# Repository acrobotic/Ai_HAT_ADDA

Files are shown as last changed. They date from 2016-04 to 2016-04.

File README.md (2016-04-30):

## Ai\_HAT\_ADDA

PCB design files (EAGLE) of a Raspberry Pi A+/B+/2/3 HAT with four 16-Bit Analog
Inputs (ADS1115) and two 12-Bit Analog Outputs (MCP4725).

## Description

Visit our online shop at:

   * https://acrobotic.com/

Designed by ACROBOTIC Industries.  Please consider buying products from us to 
help fund future Open-Source projects like this! We’ll always put our best 
effort in every project, and release all our design files and code for you to 
use. 

## License

Released under the Creative Commons Attribution, Share-Alike license. Please 
check LICENSE.txt for more information. All text above must be included in any 
redistribution.

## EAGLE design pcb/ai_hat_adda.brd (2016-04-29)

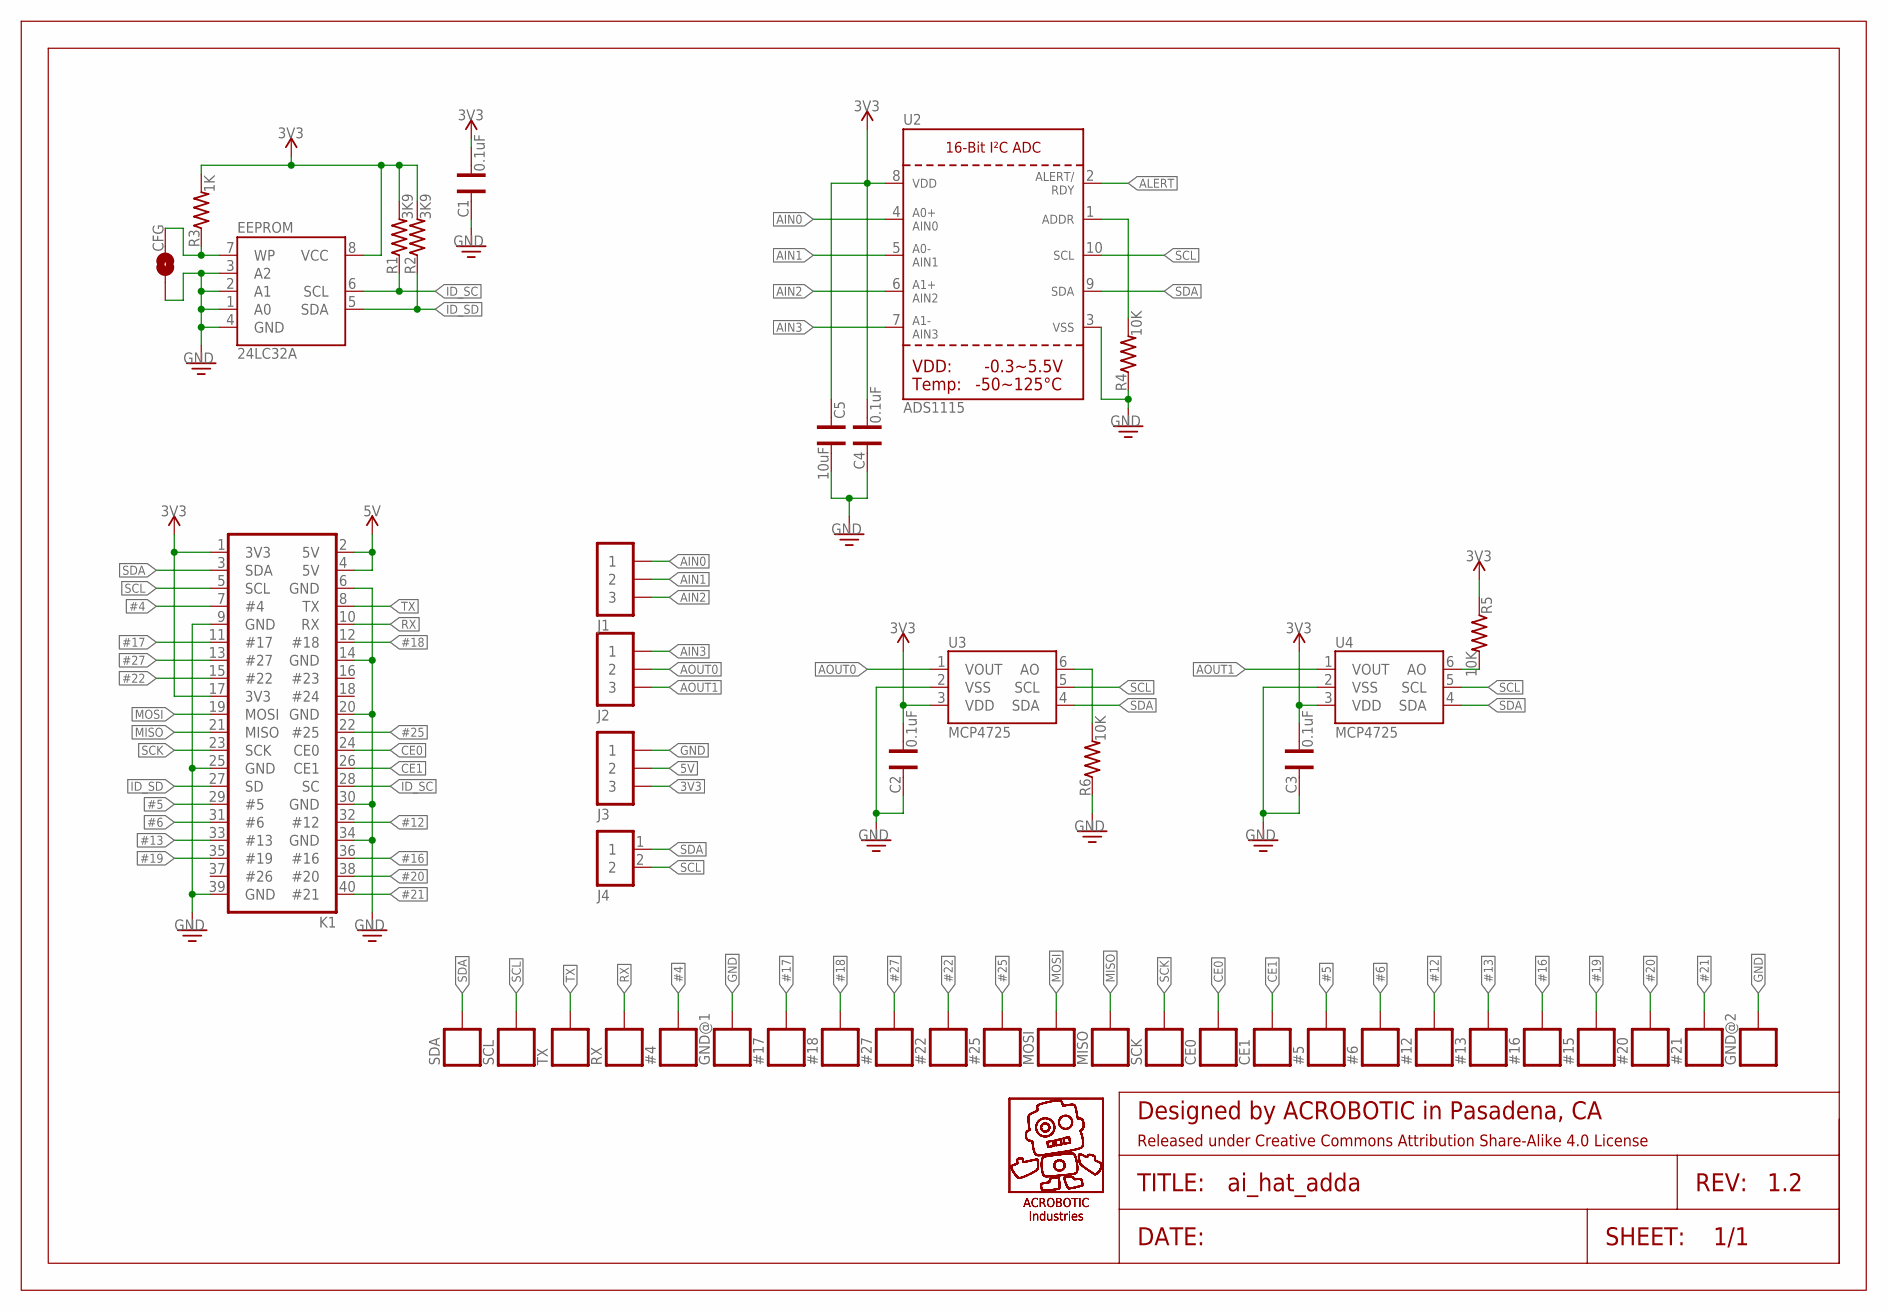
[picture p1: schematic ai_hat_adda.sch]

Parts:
#4, #5, #6, #12, #13, #15, #16, #17, #18, #20, #21, #22, #25, #27: 1X01-SM
C1: 0.1uF; CAP-0603
C2, C3, C4: 0.1uF; CAP-0402
C5: 10uF; CAP-0402
CE0, CE1: 1X01-SM
CFG: 1X02-SJ-NO
EEPROM: 24LC32A; SO08-EIAJ
FRAME1: FRAME-LETTER; CREATIVE-COMMONS
GND@1, GND@2: 1X01-SM
J1, J2, J3: 1X03ST; 1X03-ST
J4: 1X02ST; 1X02-ST
K1: 2X20-RPI-ALT
MISO: 1X01-SM
MOSI: 1X01-SM
R1, R2: 3K9; RES-0603; TOLERANCE 5%
R3: 1K; RES-0603; TOLERANCE 5%
R4, R5, R6: 10K; RES-0402
RX: 1X01-SM
SCK: 1X01-SM
SCL: 1X01-SM
SDA: 1X01-SM
TX: 1X01-SM
U2: ADS1115; MSOP10
U3, U4: MCP4725; SOT23-6
U$9, U$10: AI-LOGOXS; AI-LOGO-XS

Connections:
3V3: C1.1, C2.1, C3.1, C4.1, C5.2, EEPROM.8 (VCC), J3.3, K1.1 (3V3), K1.17 (3V3), R1.2, R2.2, R3.2, R5.1, U2.8 (VDD), U3.3 (VDD), U4.3 (VDD)
5V: J3.2, K1.2 (5V), K1.4 (5V)
#4: #4.1, K1.7 (#4)
#5: #5.1, K1.29 (#5)
#6: #6.1, K1.31 (#6)
#12: #12.1, K1.32 (#12)
#13: #13.1, K1.33 (#13)
#16: #16.1, K1.36 (#16)
#17: #17.1, K1.11 (#17)
#18: #18.1, K1.12 (#18)
#19: #15.1, K1.35 (#19)
#20: #20.1, K1.38 (#20)
#21: #21.1, K1.40 (#21)
#22: #22.1, K1.15 (#22)
#25: #25.1, K1.22 (#25)
#27: #27.1, K1.13 (#27)
AIN0: J1.1, U2.4 (AIN0)
AIN1: J1.2, U2.5 (AIN1)
AIN2: J1.3, U2.6 (AIN2)
AIN3: J2.1, U2.7 (AIN3)
ALERT: U2.2 (ALERT/RDY)
AOUT0: J2.2, U3.1 (VOUT)
AOUT1: J2.3, U4.1 (VOUT)
CE0: CE0.1, K1.24 (CE0)
CE1: CE1.1, K1.26 (CE1)
GND: C1.2, C2.2, C3.2, C4.2, C5.1, CFG.1, EEPROM.1 (A0), EEPROM.2 (A1), EEPROM.3 (A2), EEPROM.4 (GND), GND@1.1, GND@2.1, J3.1, K1.6 (GND), K1.9 (GND), K1.14 (GND), K1.20 (GND), K1.25 (GND), K1.30 (GND), K1.34 (GND), K1.39 (GND), R4.1, R6.1, U2.3 (VSS), U3.2 (VSS), U4.2 (VSS)
ID_SC: EEPROM.6 (SCL), K1.28 (SC), R1.1
ID_SD: EEPROM.5 (SDA), K1.27 (SD), R2.1
MISO: K1.21 (MISO), MISO.1
MOSI: K1.19 (MOSI), MOSI.1
unnamed: R4.2, U2.1 (ADDR)
unnamed: R6.2, U3.6 (AO)
unnamed: CFG.2, EEPROM.7 (WP), R3.1
unnamed: R5.2, U4.6 (AO)
RX: K1.10 (RX), RX.1
SCK: K1.23 (SCK), SCK.1
SCL: J4.2, K1.5 (SCL), SCL.1, U2.10 (SCL), U3.5 (SCL), U4.5 (SCL)
SDA: J4.1, K1.3 (SDA), SDA.1, U2.9 (SDA), U3.4 (SDA), U4.4 (SDA)
TX: K1.8 (TX), TX.1

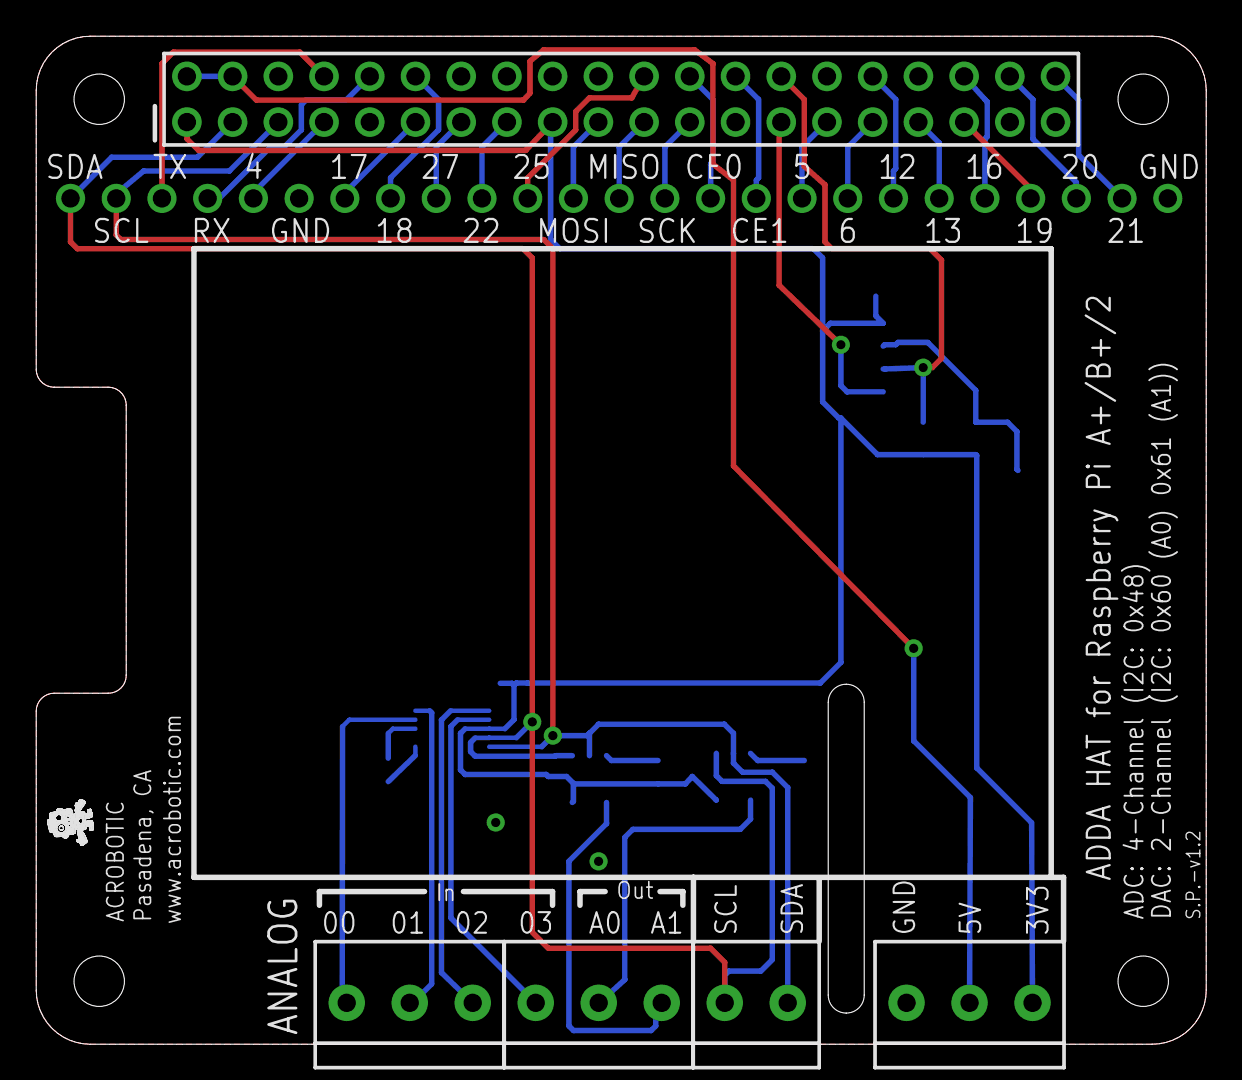
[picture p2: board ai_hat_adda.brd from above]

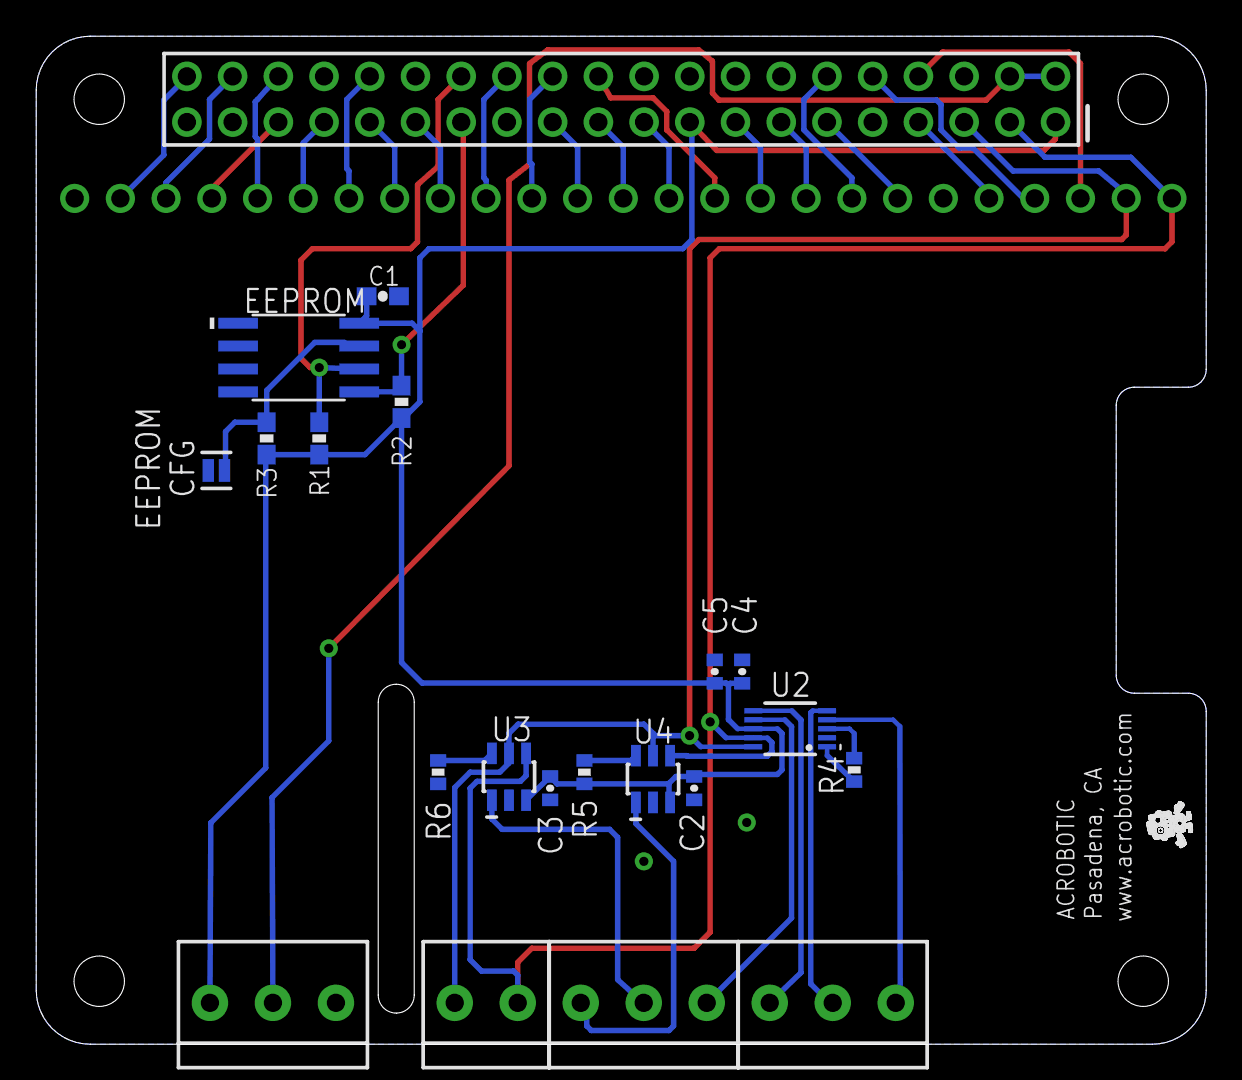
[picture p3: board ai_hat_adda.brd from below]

Board: 2 copper layers, 65.0 x 56.0 mm, 49 parts (17 on the bottom side), 38 nets.

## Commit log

2014-12-26 Small silkscreen change.
    [ai_hat_perma.brd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]
2014-12-28 updating supply to LEDs
    [ai_hat_perma.brd, ai_hat_perma.sch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]
2015-04-24 latest update
    [ai_hat_adda.brd, ai_hat_adda.sch, ai_hat_proto.brd]
2015-04-24 fixed accidental merger with Proto HAT. adding gerbers.
    [ai_hat_adda.gbl, ai_hat_adda.gbo, ai_hat_adda.gbs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]
2015-04-25 minor silkscreen updates. added 3V3 output.
    [ai_hat_adda.brd, ai_hat_adda.sch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]
2015-06-29 fixed tracing problem.
    [ai_hat_adda.brd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]

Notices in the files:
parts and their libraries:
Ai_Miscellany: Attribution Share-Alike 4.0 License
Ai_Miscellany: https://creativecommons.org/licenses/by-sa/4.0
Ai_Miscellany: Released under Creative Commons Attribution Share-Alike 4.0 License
